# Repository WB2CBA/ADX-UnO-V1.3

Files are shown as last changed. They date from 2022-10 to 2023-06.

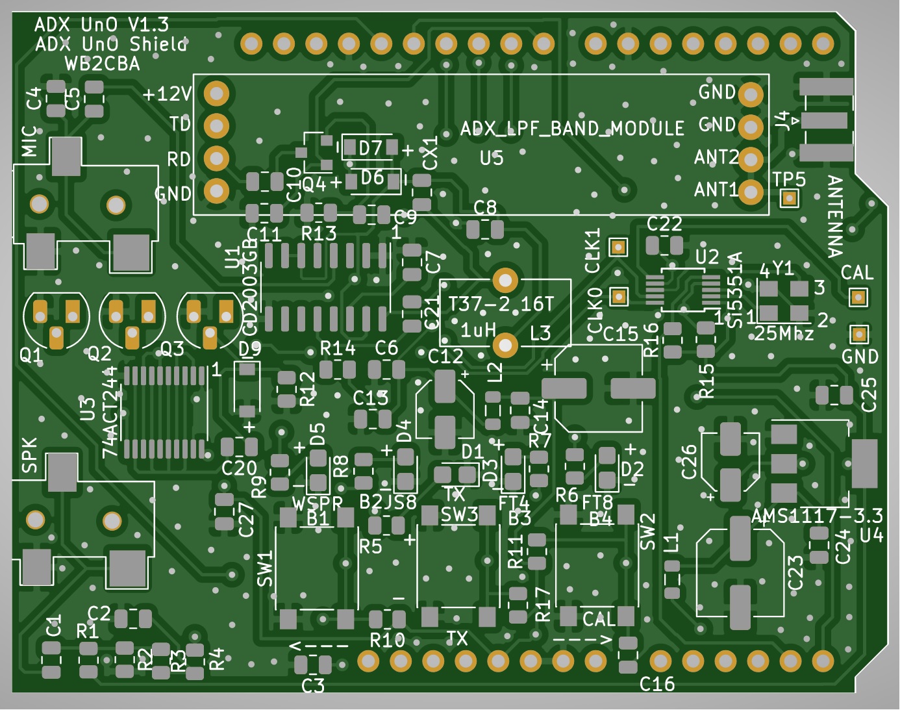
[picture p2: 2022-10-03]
ADX UnO PCB Layouts/ADX Uno Component Layout.jpg

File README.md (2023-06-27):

# ADX-UnO-V1.3

- UPDATE: 27-06-2023

- ADX UnO V1.3 is now fully open source! All SMT production files are under Production Files folder.

- I also added a Guide on how to order SMT manufactured PCBs from JLCPCB PCB production Company.

- ENJOY!:)

ADX UnO is an Arduino Uno based HF Digital Modes Transceiver. ADX is abbreviation for Arduino Digital Xceiver. 

ADX UnO is based on ADX – Arduino based Digital Modes Transceiver design.

https://antrak.org.tr/blog/adx-arduino-digital-transceiver/

ADX UnO is a mono band digital modes optimized HF transceiver that can be plugged on top of an Arduino Uno board to create a 3.5 watts average RF Output power 
QRP portable HF Digital Modes capable transceiver.  ADX UnO can cover four pre-programmed bands one band at a time by swapping Band LPF Filter Modules.

It can operate on any of the pre-programmed four bands of 80m,40m,30m,20m, 17m, 15m and 10m bands and operates on four of the most popular digital modes, FT8, FT4, JS8call and WSPR.

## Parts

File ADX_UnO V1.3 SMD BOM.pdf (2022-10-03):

Comment | Designator | Footprint
100nF | C1,C3,C4,C6,C7,C8,C13,C14,C16,C20,C21,C22,C24,C25,C27 | Capacitor_SMD:C_0805_2012Metric
10uF/16V | C12,C26 | Capacitor_SMD:CP_Elec_4x5.4
100uF/16V | C15,C23 | Capacitor_SMD:CP_Elec_6.3x7.7
10nF | C2,C10,C11 | Capacitor_SMD:C_0805_2012Metric
1uF | C5 | Capacitor_SMD:C_0805_2012Metric
680pF | C9 | Capacitor_SMD:C_0805_2012Metric
TX | D1 | LED_SMD:LED_0805_2012Metric_Castellated
FT8 | D2 | LED_SMD:LED_0805_2012Metric_Castellated
FT4 | D3 | LED_SMD:LED_0805_2012Metric_Castellated
JS8 | D4 | LED_SMD:LED_0805_2012Metric_Castellated
WSPR | D5 | LED_SMD:LED_0805_2012Metric_Castellated
1N4148 | D6,D7,D9 | Diode_SMD:D_SOD-123
SPK | J1 | uSDX_MONO_PCB_Library:Jack_3.5mm_PJ-320B-SMT_Horizontal_CORR
MIC | J2 | uSDX_MONO_PCB_Library:Jack_3.5mm_PJ-320B-SMT_Horizontal_CORR
100uH | L1,L2 | Inductor_SMD:L_0805_2012Metric
MMBF170 | Q4 | Package_TO_SOT_SMD:SOT-23
470k | R1 | Resistor_SMD:R_0805_2012Metric
2.7k | R12 | Resistor_SMD:R_0805_2012Metric
| 100 R14 | Resistor_SMD:R_0805_2012Metric
4.7k | R2,R15,R16 | Resistor_SMD:R_0805_2012Metric
10k | R3,R4,R10,R11,R17 | Resistor_SMD:R_0805_2012Metric
1k | R5,R6,R7,R8,R9,R13 | Resistor_SMD:R_0805_2012Metric
UP | SW1 | Button_Switch_SMD:SW_Push_1P1T_NO_6x6mm_H9.5mm
DOWN/CAL | SW2 | Button_Switch_SMD:SW_Push_1P1T_NO_6x6mm_H9.5mm
TX | SW3 | Button_Switch_SMD:SW_Push_1P1T_NO_6x6mm_H9.5mm
Si5351A | U2 | Package_SO:MSOP-10_3x3mm_P0.5mm
74ACT244 | U3 | Package_SO:TSSOP-20_4.4x6.5mm_P0.65mm
AMS1117-3.3 | U4 | Package_TO_SOT_SMD:SOT-223-3_TabPin2
25Mhz | Y1 | Crystal:Crystal_SMD_SeikoEpson_FA238V-4Pin_3.2x2.5mm

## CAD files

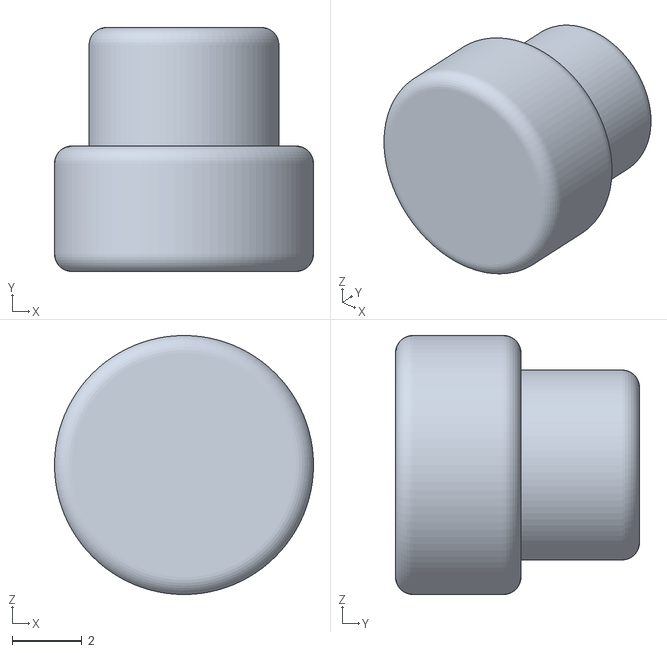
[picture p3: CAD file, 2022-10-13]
ADX UnO 3D printed case Files/KeesButton v4.stl
7.43 x 7.00 x 7.43

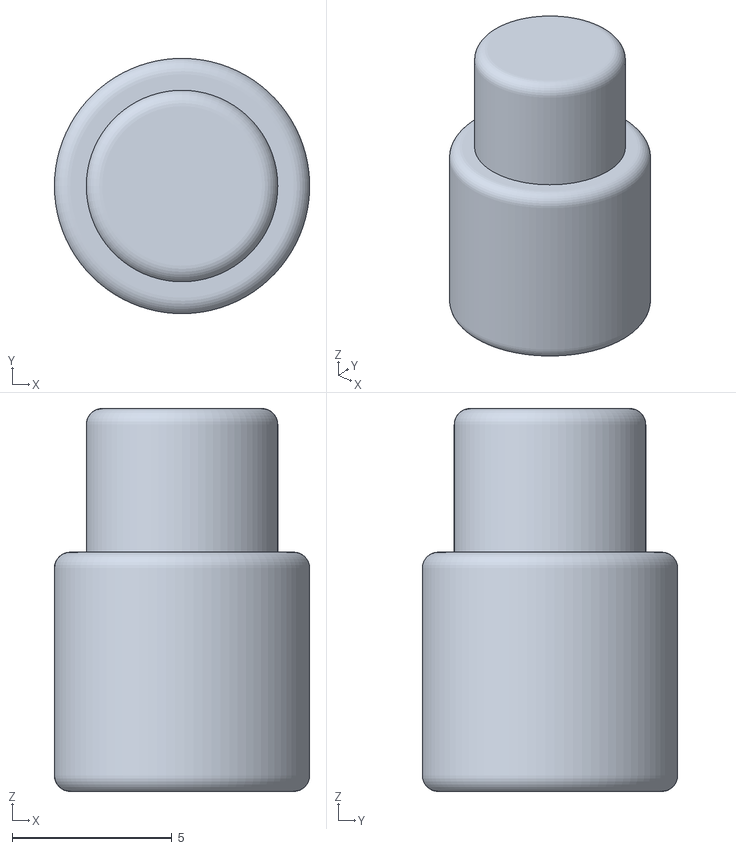
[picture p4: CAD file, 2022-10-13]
ADX UnO 3D printed case Files/button.stl
8.00 x 8.00 x 12.0

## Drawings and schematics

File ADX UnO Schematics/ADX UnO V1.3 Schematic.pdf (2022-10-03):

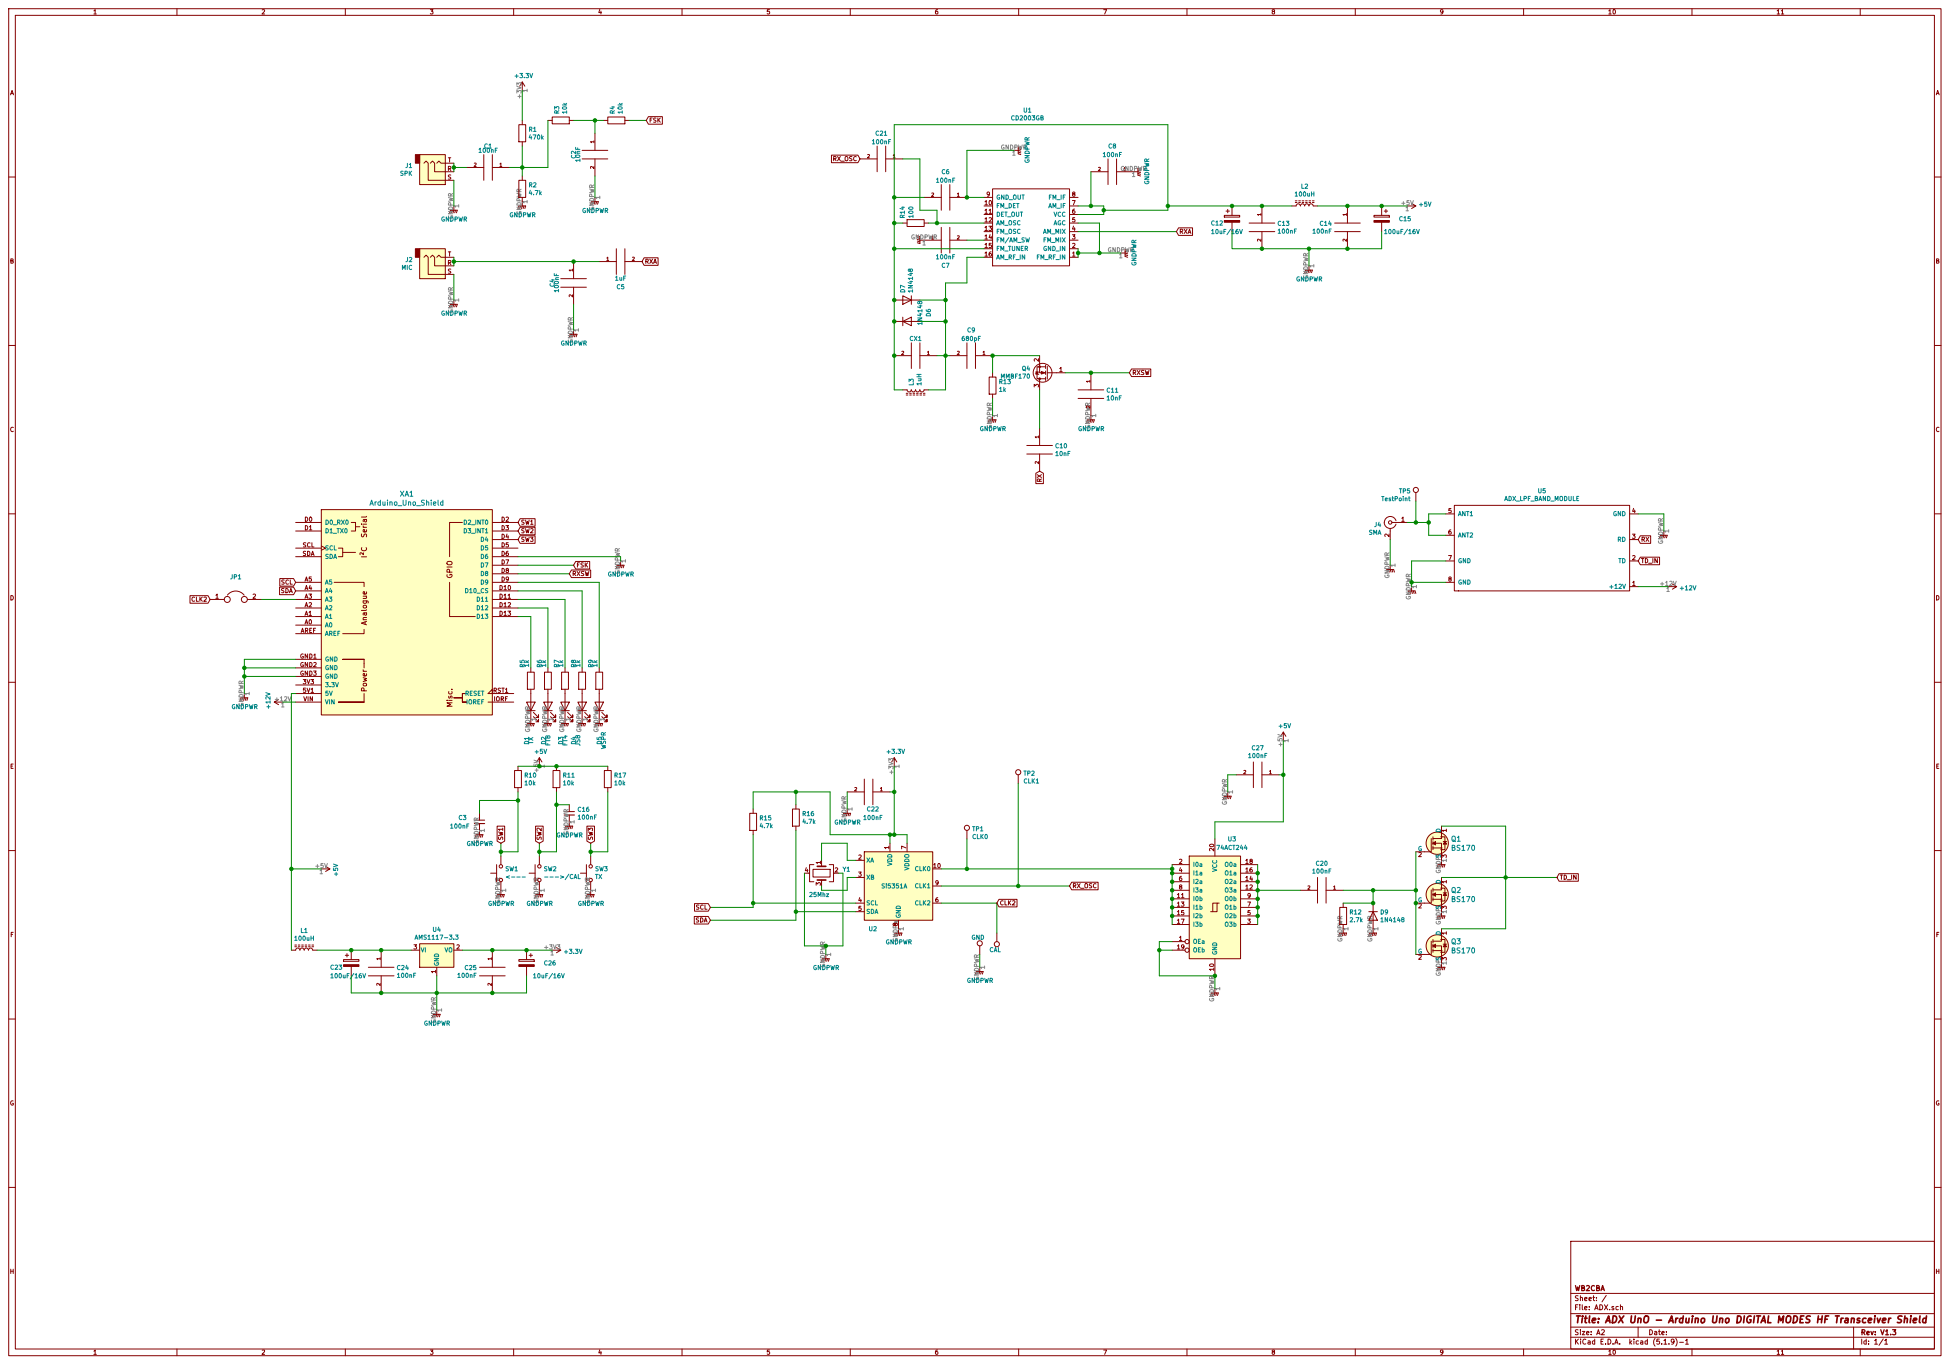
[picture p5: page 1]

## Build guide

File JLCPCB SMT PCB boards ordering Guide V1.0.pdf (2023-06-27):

# SMT PCB boards - JLCPCB ordering guide:

Now let’s talk about the most important subject! How we are going to get these SMD boards manufactured! Here is a short guide for ordering SMD manufactured boards from JLCPCB!

Surface mount parts might be intimidating for most of us. They need healthy eyes and steady hands to solder. This SMT pcb manufacturing service cures that problem by manufacturing PCBs and installing all smd parts on them in a controlled factory environment! An example of cost for this service: uSDX SOTA Main board will cost you less than 15 US Dollars each for a batch of 10 PCB orders including DHL shipping! This means a PCB with 85% of parts assembled including that SI5351 beast! The trick is the more units of pcb you order the less you pay for one pcb in cost.

The reason for that is there are certain one time fee costs JLCPCB adds to their invoice. Those are SMT setting up fee, extended parts fee etc. These are one time cost charges for each pcb order batch. So if we order 5 pieces of pcb that surcharge cost will be shared by 5 pcbs. If we order 30 pcbs then that surcharge will be divided by 30 and will be less per pcb. That’s why it is always order pcbs in larger quantities as a group buy. Ok how we will do this smt ordering business!

I’ll explain this as simple as possible in steps:

1- We will need Production files:
In order to place an order a SMT manufactured PCB from JLCPCB we need three files
– GERBER file (contains all the files to manufacture the PCB board itself)
– BOM File(contains all smd parts, their smd footprints and JLCPCB stock numbers for each part)
– Foot print position file (it is also called as centroid file – coordinates of each smd part on the pcb for pick and place robot)

All these files are included in each boards ZIP file under production file directory.

2- Create an account on www.jlcpcb.com. Follow instructions on their site.

3- After creating your account with all your credentials click on instant quote button

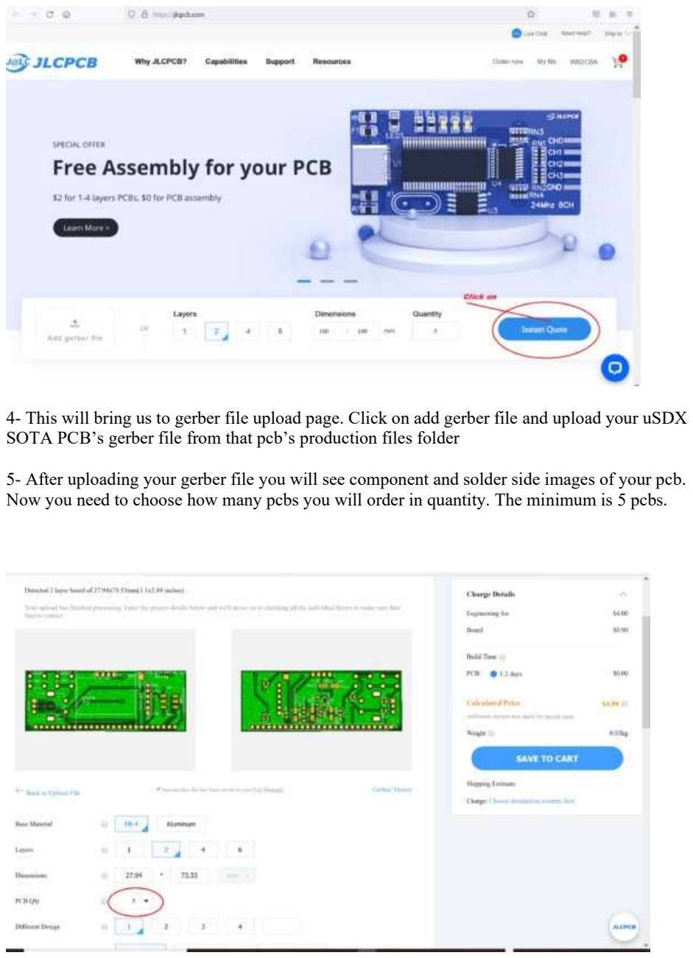
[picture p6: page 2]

4- This will bring us to gerber file upload page. Click on add gerber file and upload your uSDX SOTA PCB’s gerber file from that pcb’s production files folder

5- After uploading your gerber file you will see component and solder side images of your pcb. Now you need to choose how many pcbs you will order in quantity. The minimum is 5 pcbs.

6- Now scroll down the same gerber upload page until you see the Free SMT Assembly for your PCB slide switch which should be light grey inactive position. Now slide it to activate. You should see below screen with top and bottom sides of your PCB. In this case I used uSDX SOTA 128×64 OLED Display as an example. In this display smd populated side is bottom side so I chose assemble bottom side. Now without touching anything else first click on Confirm then click on NEXT.

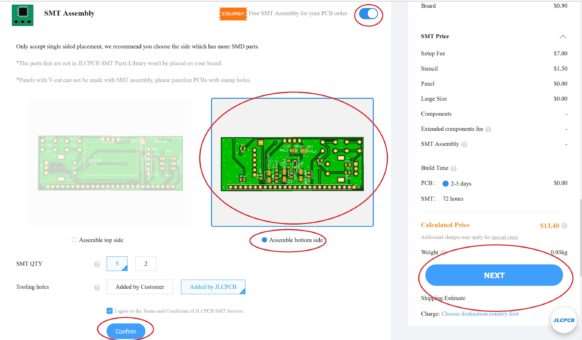
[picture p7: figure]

7- Now we will come to this next screen after clicking on NEXT. This is where we upload our BOM file and footprint position file which is marked as CPL button. These files are in your PCB’s production files. First click on Add BOM File button and upload BOM file from production files folder. Then click on Add CPL File Button and upload your footprint position file from your PCB’s production files.

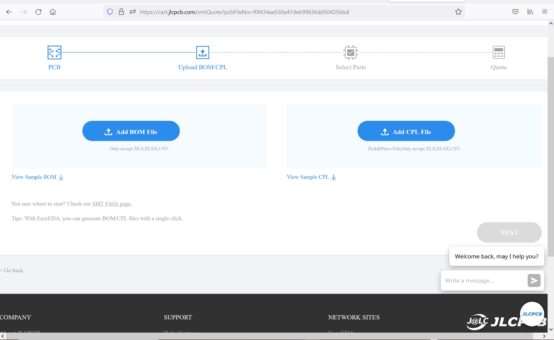
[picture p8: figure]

8- After uploading BOM and CPL files this is the screen which shows all the components of our PCB for SMT manufacturing. This table will show all the component part numbers, total number of each component that will be used for the whole batch of PCBs. Also total cost of each part for the whole batch of PCB order.

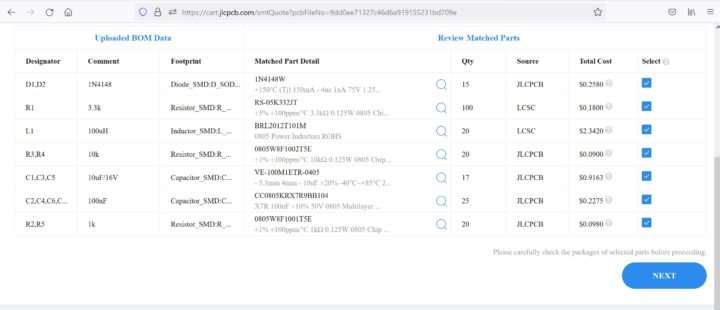
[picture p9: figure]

The most important column in this table is those blue check marks. If you see a blue check mark then it tells you that they have your components and those components have enough stock to manufacture your boards! If one or more parts is not in stock which can happen nowadays as there is chip shortage going on you might get an inventory shortage warning in place of blue check mark. Now JLCPCB does not have that part in stock and can’t pick and place that part and that part will be omitted from pick and place manufacturing. It’s not the end of the world! You can still get your pcb manufactured and hand solder those parts when you receive your pcbs.

Here is an example for that:

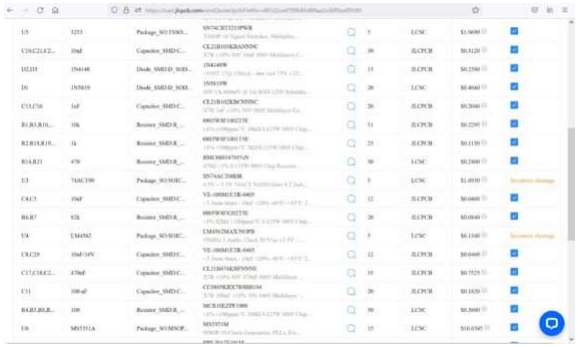
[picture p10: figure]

This is parts list for uSDX SOTA Main PCB. Two parts, 74ACT00DWR and LM4562 is out of stock. The rest of the parts are in stock so no problem with them. We will just order the PCBS and hand solder those parts afterwards. They are easy to solder smd parts.
Now click on NEXT to go to the next ordering screen.

9- This is the next screenshot you will come across which shows your PCB and virtual pick and place finished product layout of your pcb. There might be orientation errors in this PCB virtual parts layout time to time, don’t worry about that. JLCPCB will review your pcb layout and pick and place file and then match those positions. After you ordered your PCB for SMT manufacturing they will review it and correct those mismatches. After this review when you access your account you will see a DFM file icon. If you click on that it will show your previous and manufacturing virtual corrected layout.

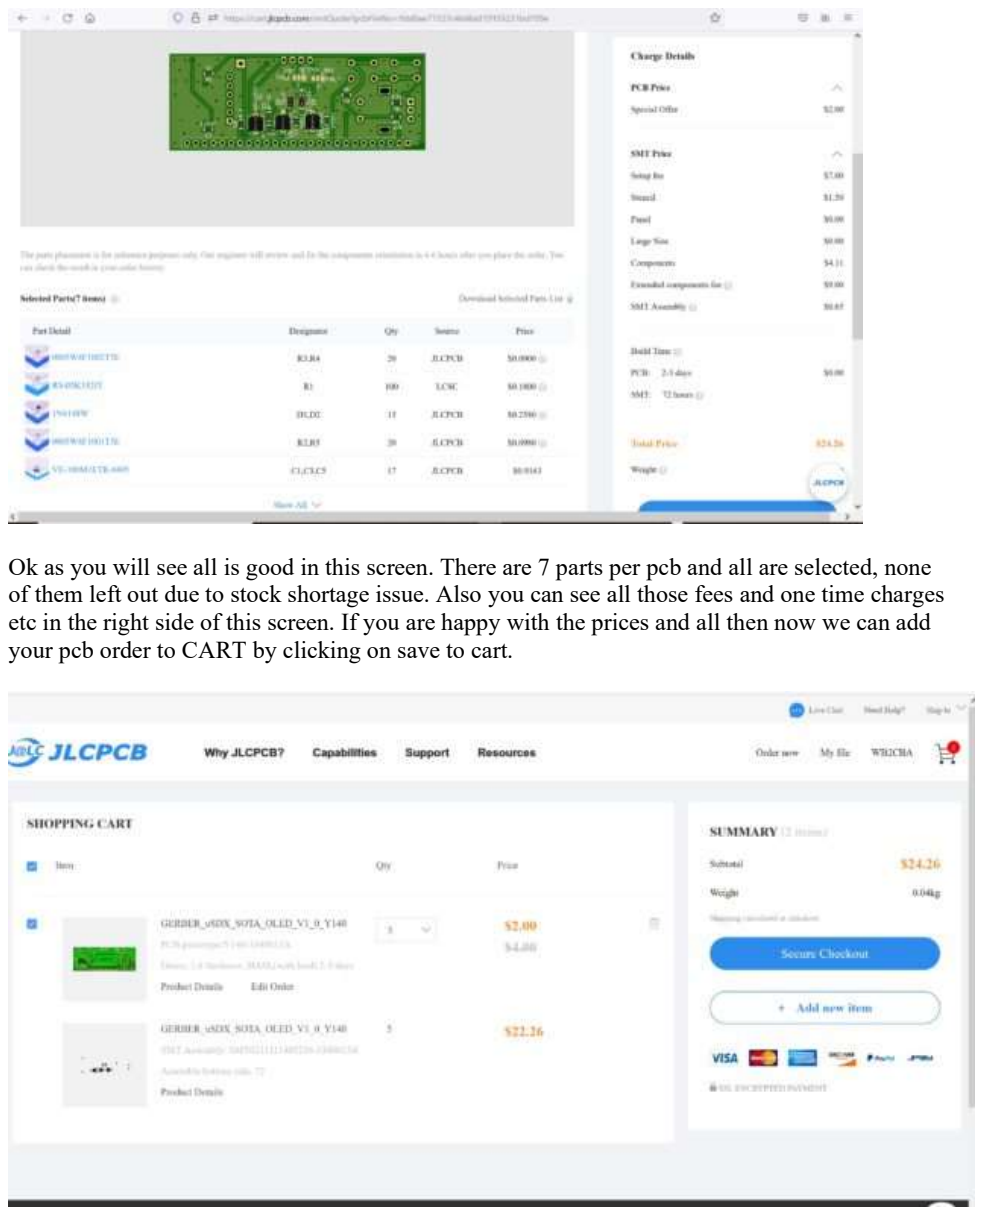
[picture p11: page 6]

Ok as you will see all is good in this screen. There are 7 parts per pcb and all are selected, none of them left out due to stock shortage issue. Also you can see all those fees and one time charges etc in the right side of this screen. If you are happy with the prices and all then now we can add your pcb order to CART by clicking on save to cart.

This CART screen will show your total cost for that ordered pcb batch. Now press on secure checkout and follow the procedure by verifying your address then shipment type and then payment etc.

Now let’s talk again about our nightmare case where some of the parts were out of stock!

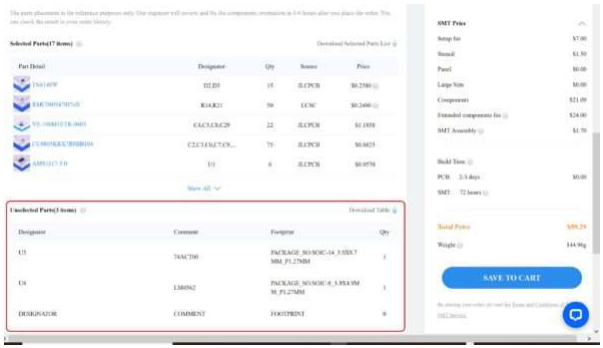
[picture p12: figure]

In uSDX SOTA Main board PCB case two parts were out of stock and we still advanced the order and clicked next. Now as outlined in red box those parts are out of production and not listed on main parts list and will not be shown on virtual smt mounted pcb layout. We can still go ahead with the order and save to cart and get main board pcbs manufactured and when we outsource those parts we can hand solder them. It’s not the end of the world!

Personally I encourage fellow DIY lover hams to give it a try on ordering uSDX SOTA boards smt manufactured from JLCPCB. You will be surprised how cheap they will be for an order of 10 boards. Even with minimum 5 boards is reasonable price. The biggest benefit is that 85% of the transceiver rig is coming to your door step already soldered in!

Barb WB2CBA
12/05/2021 NY, USA

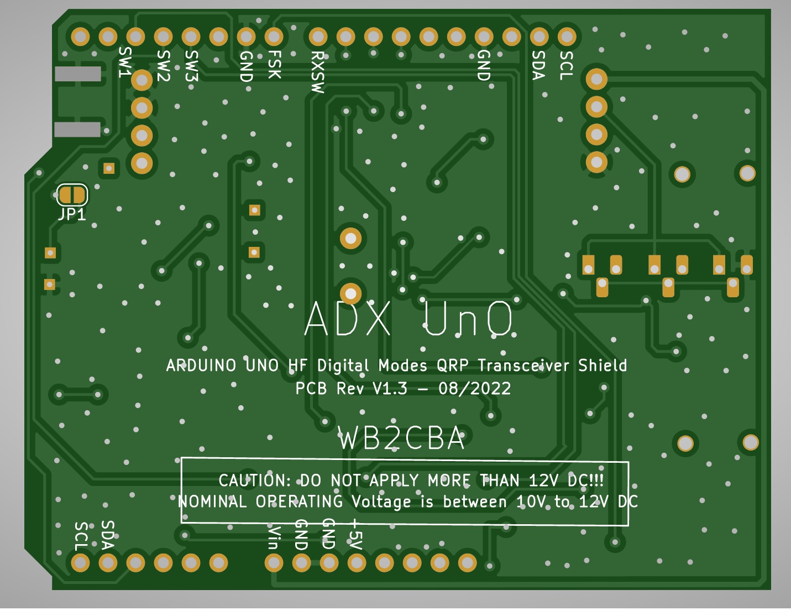
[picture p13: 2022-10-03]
ADX UnO PCB Layouts/ADX Uno Solder side Layout.jpg

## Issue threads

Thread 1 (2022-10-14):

Question about JLCPCB order

gembiart, 2022-10-14:
Hello, I'm trying order PCB (from your gerber files) with BOM xlsx file. On JLCPCB website is also ADD CPL FILE (with coordinates I suppose)
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
Can you share with this CPL file ? I didn't see it at your project.

Regards
SQ5ART

WB2CBA, 2022-10-15:
Hi,

I released ADX Uno as Open source for DIY, meaning anyone can produce a  pcb and build one by reflow or hand solder.
CPL file  is for pick and place mass production and I reserve the rights of pick and place production and I won’t release at least for now. I hope this clarifies your query.

73

Barb WB2CBA

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

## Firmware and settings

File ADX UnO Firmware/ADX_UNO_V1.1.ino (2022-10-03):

//*********************************************************************************************************
//********************* ADX UNO - ARDUINO UNO  DIGITAL MODES 4 BAND HF TRANSCEIVER ***************************
//********************************* Write up start: 02/01/2022 ********************************************
// FW VERSION: ADX_UNO_V1.1 - Version release date: 08/05/2022
// Barb(Barbaros ASUROGLU) - WB2CBA - 2022
//  Version History
//  V1.0  Modified Calibration EEPROM to protect R/W cycle of EEPROM.
//  V1.1 10m/28Mhz band support added.
//*********************************************************************************************************
// Required Libraries
// ----------------------------------------------------------------------------------------------------------------------
// Etherkit Si5351 (Needs to be installed via Library Manager to arduino ide) - SI5351 Library by Jason Mildrum (NT7S) - https://github.com/etherkit/Si5351Arduino
//*****************************************************************************************************
//* IMPORTANT NOTE: Use V2.1.3 of NT7S SI5351 Library. This is the only version compatible with ADX!!!*
//*****************************************************************************************************
// Arduino "Wire.h" I2C library(built-into arduino ide)
// Arduino "EEPROM.h" EEPROM Library(built-into arduino ide)
//*************************************[ LICENCE and CREDITS ]*********************************************
//  FSK TX Signal Generation code by: Burkhard Kainka(DK7JD) - http://elektronik-labor.de/HF/SDRtxFSK2.html
//  SI5351 Library by Jason Mildrum (NT7S) - https://github.com/etherkit/Si5351Arduino

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
//*****************[ SI5351 VFO CALIBRATION PROCEDURE ]****************************************
// For SI5351 VFO Calibration Procedure follow these steps:
// 1 - Connect CAL test point and GND test point on ADX PCB to a Frequency meter or Scope that can measure 1 Mhz up to 1Hz accurately.
// 2 - Press SW2 / --->(CAL) pushbutton and hold.
// 4-  Power up with 12V or with 5V by using arduino USB socket while still pressing SW2 / --->(CAL) pushbutton. 
// 5 - FT8 and WSPR LEDs will flash 3 times and stay lit. Now Release SW2 / --->(CAL). Now Calibration mode is active.
// 6 - Using SW1(<---) and SW2(--->) pushbuttons change the Calibration frequency.
// 7 - Try to read 1 Mhz = 1000000 Hz exact on  Frequency counter or Oscilloscope. 
//     The waveform is Square wave so freqency calculation can be performed esaily.
// 8 - If you read as accurate as possible 1000000 Hz then calibration is done. 
// 9 - Now we must save this calibration value to EEPROM location. 
//     In order to save calibration value, press TX button briefly. TX LED will flash 3 times which indicates that Calibration value is saved.
// 10- Power off ADX.
 
//*******************************[ LIBRARIES ]*************************************************
#include <si5351.h>
#include "Wire.h"
#include <EEPROM.h>
//*******************************[ VARIABLE DECLERATIONS ]*************************************
uint32_t val;
int temp;
uint32_t val_EE; 
int addr = 0;
int mode;
unsigned long freq; 
unsigned long freq1;
int32_t cal_factor;
int TX_State = 0;

unsigned long Cal_freq = 1000000UL; // Calibration Frequency: 1 Mhz = 1000000 Hz
unsigned long F_FT8;
unsigned long F_FT4; 
unsigned long F_JS8;
unsigned long F_WSPR;
int Band_slot;
int Band = 0;
int UP_State;
int DOWN_State;
int TXSW_State;
int Bdly = 250;
// **********************************[ DEFINE's ]***********************************************
#define UP 2    // UP Switch
#define DOWN 3  // DOWN Switch
#define TXSW 4  // TX Switch

#define TX 13 //TX LED
#define WSPR  9 //WSPR LED 
#define JS8  10 //JS8 LED
#define FT4  11 //FT4 LED
#define FT8 12 //FT8 LED

#define RX  8 // RX SWITCH
#define SI5351_REF 		25000000UL  //change this to the frequency of the crystal on your si5351’s PCB, usually 25 or 27 MHz

//**********************************[ BAND SELECT ]************************************************
// ADX can support up to 4 bands on board. Those 4 bands needs to be assigned to Band1 ... Band4 from supported 8 bands.
// To change bands press SW1 and SW2 simultaneously. Band LED will flash 3 times briefly and stay lit for the stored band. also TX LED will be lit to indicate
// that Band select mode is active. Now change band bank by pressing SW1(<---) or SW2(--->). When desired band bank is selected press TX button briefly to exit band select mode. 
// Now the new selected band bank will flash 3 times and then stored mode LED will be lit. 
// TX won't activate when changing bands so don't worry on pressing TX button when changing bands in band mode.

// Assign your prefered bands to B1,B2,B3 and B4
// Supported Bands are: 80m, 40m, 30m, 20m,17m, 15m, 10m

int Band1 = 40; // Band 1 // These are default bands. Feel free to swap with yours
int Band2 = 30; // Band 2
int Band3 = 20; // Band 3
int Band4 = 17; // Band 4

Si5351 si5351;

//*************************************[ SETUP FUNCTION ]************************************** 
void setup()
{
   pinMode(UP, INPUT);
   pinMode(DOWN, INPUT);
   pinMode(TXSW, INPUT);
   
pinMode(TX, OUTPUT);
pinMode(WSPR, OUTPUT);
pinMode(JS8, OUTPUT);
pinMode(FT4, OUTPUT);
pinMode(FT8, OUTPUT);
pinMode(RX, OUTPUT);

pinMode(7, INPUT); //PD7 = AN1 = HiZ, PD6 = AN0 = 0
  
INIT();

//------------------------------- SET SI5351 VFO -----------------------------------  
   // The crystal load value needs to match in order to have an accurate calibration
  si5351.init(SI5351_CRYSTAL_LOAD_8PF, 0, 0);
  si5351.set_correction(cal_factor, SI5351_PLL_INPUT_XO);
 si5351.set_pll(SI5351_PLL_FIXED, SI5351_PLLA);
  si5351.drive_strength(SI5351_CLK0, SI5351_DRIVE_8MA);// SET For Max Power
  si5351.drive_strength(SI5351_CLK1, SI5351_DRIVE_2MA); // Set for reduced power for RX 
  
 if ( digitalRead(DOWN) == LOW ) {
Calibration();
 }
 

  TCCR1A = 0x00;
  TCCR1B = 0x01; // Timer1 Timer 16 MHz
  TCCR1B = 0x81; // Timer1 Input Capture Noise Canceller
  ACSR |= (1<<ACIC);  // Analog Comparator Capture Input
  
  pinMode(7, INPUT); //PD7 = AN1 = HiZ, PD6 = AN0 = 0
          digitalWrite(RX,LOW);

 Mode_assign(); 

}
 
//**************************[ END OF SETUP FUNCTION ]************************

//***************************[ Main LOOP Function ]**************************
void loop()
{  

       UP_State = digitalRead(UP);
          DOWN_State = digitalRead(DOWN);


if ((UP_State == LOW)&&(DOWN_State == LOW)&&(TX_State == 0)) {
   delay(100); 
 UP_State = digitalRead(UP);
    DOWN_State = digitalRead(DOWN);
if ((UP_State == LOW)&&(DOWN_State == LOW)&&(TX_State == 0)) {

    Band_Select();
    
  }
}

  

if ((UP_State == LOW)&&(DOWN_State == HIGH)&&(TX_State == 0)) {
   delay(50); 
     
UP_State = digitalRead(UP);
if ((UP_State == LOW)&&(DOWN_State == HIGH)&&(TX_State == 0)) {
mode = mode - 1;

if (mode < 1){
mode = 4;
}



addr = 40;
 EEPROM.put(addr, mode); 
                Mode_assign();
                
  }} 
   
      DOWN_State = digitalRead(DOWN);

if ((UP_State == HIGH) && (DOWN_State == LOW)&&(TX_State == 0)) {
   delay(50); 
     
DOWN_State = digitalRead(DOWN);
if ((UP_State == HIGH) && (DOWN_State == LOW)&&(TX_State == 0)) {
mode = mode + 1;

if (mode > 4){
mode = 1;
}



addr = 40;
 EEPROM.put(addr, mode); 
                    Mode_assign();
                    
  }} 

  TXSW_State = digitalRead(TXSW);

if ((TXSW_State == LOW) && (TX_State == 0)) {
   delay(50); 
     
TXSW_State = digitalRead(TXSW);
if ((TXSW_State == LOW) && (TX_State == 0)) {
  
Mode_assign();

ManualTX();

           }
  
     }

unsigned int d1,d2;
 int FSK = 10;
 int FSKtx = 0;
 while (FSK>0){
  TCNT1 = 0;
  while (ACSR &(1<<ACO)){
    if (TCNT1>65000) {break;
  }
  }  while ((ACSR &(1<<ACO))==0){
    if (TCNT1>65000) {break;}
  }
  TCNT1 = 0;
  while (ACSR &(1<<ACO)){
    if (TCNT1>65000) {break;}
  }
  d1 = ICR1;  
  while ((ACSR &(1<<ACO))==0){
    if (TCNT1>65000) {break;}
  } 
  while (ACSR &(1<<ACO)){
    if (TCNT1>65000) {break;}
  }
  d2 = ICR1;
  if (TCNT1 < 65000){
  unsigned long codefreq = 1600000000/(d2-d1);
    if (codefreq < 350000){
      if (FSKtx == 0){
        TX_State = 1;
          digitalWrite(TX,HIGH);
          digitalWrite(RX,LOW);
         
          si5351.output_enable(SI5351_CLK1, 0);   //RX off
          si5351.output_enable(SI5351_CLK0, 1);   // TX on
      }
      si5351.set_freq((freq * 100 + codefreq), SI5351_CLK0);  
      
      FSKtx = 1;
    }
  }
  else{
    FSK--;
  }
 }
  digitalWrite(TX,0);
  
    si5351.output_enable(SI5351_CLK0, 0);   //TX off
    si5351.set_freq(freq*100ULL, SI5351_CLK1);
          si5351.output_enable(SI5351_CLK1, 1);   //RX on
    TX_State = 0;
    digitalWrite(RX,HIGH);
  FSKtx = 0;

     
}
//*********************[ END OF MAIN LOOP FUNCTION ]*************************

//********************************************************************************
//******************************** [ FUNCTIONS ] *********************************
//********************************************************************************


//************************************[ MODE Assign ]**********************************

void Mode_assign(){
  
addr = 40;
EEPROM.get(addr,mode);


if ( mode == 1){
  freq1 = F_WSPR;
 digitalWrite(WSPR, HIGH); 
     digitalWrite(JS8, LOW); 
         digitalWrite(FT4, LOW); 
             digitalWrite(FT8, LOW); 

}

if ( mode == 2){
  freq1 = F_JS8;
digitalWrite(WSPR, LOW); 
     digitalWrite(JS8, HIGH); 
         digitalWrite(FT4, LOW); 
             digitalWrite(FT8, LOW); 


  
}

if ( mode == 3){
  freq1 = F_FT4;

digitalWrite(WSPR, LOW); 
     digitalWrite(JS8, LOW); 
         digitalWrite(FT4, HIGH); 
             digitalWrite(FT8, LOW); 

  
}
if ( mode == 4){
  freq1 = F_FT8;
  
digitalWrite(WSPR, LOW); 
     digitalWrite(JS8, LOW); 
         digitalWrite(FT4, LOW); 
             digitalWrite(FT8, HIGH); 

  
}
freq = freq1; 
//freq = freq1 - 1000;

}

//********************************[ END OF MODE ASSIGN ]*******************************

//*********************[ Band dependent Frequency Assign Function ]********************
void Freq_assign(){


//---------- 80m/3.5Mhz 
          if (Band == 80){

            F_FT8 = 3573000;
            F_FT4 = 3575000;
            F_JS8 = 3578000;
            F_WSPR = 3568600;
          }

//---------- 40m/7 Mhz 
          if (Band == 40){

            F_FT8 = 7074000;
            F_FT4 = 7047500;
            F_JS8 = 7078000;
            F_WSPR = 7038600;
          }


//---------- 30m/10 Mhz 
          if (Band == 30){

            F_FT8 = 10136000;
            F_FT4 = 10140000;
            F_JS8 = 10130000;
            F_WSPR = 10138700;
          }


//---------- 20m/14 Mhz 
          if (Band == 20){

            F_FT8 = 14074000;
            F_FT4 = 14080000;
            F_JS8 = 14078000;
            F_WSPR = 14095600;
          }


 //---------- 17m/18 Mhz 
          if (Band == 17){

            F_FT8 = 18100000;
            F_FT4 = 18104000;
            F_JS8 = 18104000;
            F_WSPR = 18104600;
          } 

//---------- 15m/ 21Mhz 
          if (Band == 15){

            F_FT8 = 21074000;
            F_FT4 = 21140000;
            F_JS8 = 21078000;
            F_WSPR = 21094600;
          } 
          
//---------- 10m/ 28Mhz 
          if (Band == 10){

            F_FT8 = 28074000;
            F_FT4 = 28180000;
            F_JS8 = 28078000;
            F_WSPR = 28124600;
          }
                     
}
//************************[ End of Frequency assign function ]*************************  

//******************************[ Band  Assign Function ]******************************

void Band_assign(){
digitalWrite(WSPR, LOW); 
     digitalWrite(JS8, LOW); 
         digitalWrite(FT4, LOW); 
             digitalWrite(FT8, LOW); 


addr = 50;
EEPROM.get(addr,Band_slot);

if (Band_slot == 1){
  Band = Band1;
  
digitalWrite(WSPR, HIGH); 
delay(Bdly);
digitalWrite(WSPR, LOW); 
delay(Bdly);
digitalWrite(WSPR, HIGH); 
delay(Bdly);
digitalWrite(WSPR, LOW); 
delay(Bdly);
digitalWrite(WSPR, HIGH); 
delay(Bdly);
digitalWrite(WSPR, LOW); 
delay(Bdly);
}

if (Band_slot == 2){
  Band = Band2;
  
digitalWrite(JS8, HIGH); 
delay(Bdly);
digitalWrite(JS8, LOW); 
delay(Bdly);
digitalWrite(JS8, HIGH); 
delay(Bdly);
digitalWrite(JS8, LOW); 
delay(Bdly);
digitalWrite(JS8, HIGH); 
delay(Bdly);
digitalWrite(JS8, LOW); 
delay(Bdly);
}

if (Band_slot == 3){
  Band = Band3;
  
digitalWrite(FT4, HIGH); 
delay(Bdly);
digitalWrite(FT4, LOW); 
delay(Bdly);
digitalWrite(FT4, HIGH); 
delay(Bdly);
digitalWrite(FT4, LOW); 
delay(Bdly);
digitalWrite(FT4, HIGH); 
delay(Bdly);
digitalWrite(FT4, LOW); 
delay(Bdly);
}

if (Band_slot == 4){
  Band = Band4;
  
digitalWrite(FT8, HIGH); 
delay(Bdly);
digitalWrite(FT8, LOW); 
delay(Bdly);
digitalWrite(FT8, HIGH); 
delay(Bdly);
digitalWrite(FT8, LOW); 
delay(Bdly);
digitalWrite(FT8, HIGH); 
delay(Bdly);
digitalWrite(FT8, LOW); 
delay(Bdly);
}


delay(1000);

Freq_assign();

Mode_assign();


}
//***************************[ End of Band assign function ]***************************  


//*******************************[ Manual TX FUNCTION ]********************************
void ManualTX(){
 
 digitalWrite(RX,LOW);
          si5351.output_enable(SI5351_CLK1, 0);   //RX off


TXON:  

TXSW_State = digitalRead(TXSW);

 
digitalWrite(TX,1);
    si5351.set_freq(freq1*100ULL, SI5351_CLK0);
    si5351.output_enable(SI5351_CLK0, 1);   //TX on
    TX_State = 1;
    
  if (TXSW_State == HIGH) {
goto EXIT_TX;

}
   goto TXON;




EXIT_TX:
digitalWrite(TX,0); 
    si5351.output_enable(SI5351_CLK0, 0);   //TX off
    TX_State = 0;

}

//********************************[ END OF Manual TX ]*********************************

//******************************[ BAND SELECT Function]********************************
void Band_Select(){

digitalWrite(TX,1);
addr = 50; 
EEPROM.get(addr,Band_slot);

digitalWrite(WSPR,LOW); 
digitalWrite(JS8, LOW); 
digitalWrite(FT4, LOW); 
digitalWrite(FT8, LOW); 


if (Band_slot == 1){
 
  
digitalWrite(WSPR, HIGH); 
delay(Bdly);
digitalWrite(WSPR, LOW); 
delay(Bdly);
digitalWrite(WSPR, HIGH); 
delay(Bdly);
digitalWrite(WSPR, LOW); 
delay(Bdly);
digitalWrite(WSPR, HIGH); 
delay(Bdly);
digitalWrite(WSPR, LOW); 
delay(Bdly);
}

if (Band_slot == 2){
  
digitalWrite(JS8, HIGH); 
delay(Bdly);
digitalWrite(JS8, LOW); 
delay(Bdly);
digitalWrite(JS8, HIGH); 
delay(Bdly);
digitalWrite(JS8, LOW); 
delay(Bdly);
digitalWrite(JS8, HIGH); 
delay(Bdly);
digitalWrite(JS8, LOW); 
delay(Bdly);
}

if (Band_slot == 3){
  
digitalWrite(FT4, HIGH); 
delay(Bdly);
digitalWrite(FT4, LOW); 
delay(Bdly);
digitalWrite(FT4, HIGH); 
delay(Bdly);
digitalWrite(FT4, LOW); 
delay(Bdly);
digitalWrite(FT4, HIGH); 
delay(Bdly);
digitalWrite(FT4, LOW); 
delay(Bdly);
}

if (Band_slot == 4){
  
digitalWrite(FT8, HIGH); 
delay(Bdly);
digitalWrite(FT8, LOW); 
delay(Bdly);
digitalWrite(FT8, HIGH); 
delay(Bdly);
digitalWrite(FT8, LOW); 
delay(Bdly);
digitalWrite(FT8, HIGH); 
delay(Bdly);
digitalWrite(FT8, LOW); 
delay(Bdly);
}

Band_cont:
 
if (Band_slot == 1){
 
  
digitalWrite(WSPR, HIGH); 
digitalWrite(JS8, LOW); 
digitalWrite(FT4, LOW); 
digitalWrite(FT8, LOW); 
}

if (Band_slot == 2){
  
  
digitalWrite(JS8, HIGH); 
digitalWrite(WSPR, LOW); 
digitalWrite(FT4, LOW); 
digitalWrite(FT8, LOW); 

}

if (Band_slot == 3){
digitalWrite(FT4, HIGH); 
digitalWrite(WSPR, LOW); 
digitalWrite(JS8, LOW); 
digitalWrite(FT8, LOW); 

  

}

if (Band_slot == 4){
digitalWrite(JS8, LOW); 
digitalWrite(WSPR, LOW); 
digitalWrite(FT4, LOW); 
digitalWrite(FT8, HIGH); 
 
  }


 UP_State = digitalRead(UP);
          DOWN_State = digitalRead(DOWN);
    
if ((UP_State == LOW)&&(DOWN_State == HIGH)) {
   delay(100); 
     
UP_State = digitalRead(UP);
if ((UP_State == LOW)&&(DOWN_State == HIGH)) {
Band_slot = Band_slot - 1;

if (Band_slot < 1){
Band_slot = 4;
        }
     }
  } 
   
if ((UP_State == HIGH)&&(DOWN_State == LOW)) {
   delay(100); 
     
DOWN_State = digitalRead(DOWN);
if ((UP_State == HIGH)&&(DOWN_State == LOW)) {
Band_slot = Band_slot + 1;

if (Band_slot > 4){
Band_slot = 1;
       }
    }
 }
                                                

TX_State = digitalRead(TXSW);

if (TX_State == LOW) {
   delay(100); 
 
    TX_State = digitalRead(TXSW);
if (TX_State == LOW) {
  
digitalWrite(TX,0); 

   goto Band_exit;
    
  }
} 

goto Band_cont;

Band_exit:

addr = 50;
 EEPROM.put(addr, Band_slot); 


 Band_assign();


}
  
//*********************************[ END OF BAND SELECT ]*****************************




//************************** [SI5351 VFO Calibration Function] ************************

void Calibration(){

digitalWrite(FT8, LOW);
digitalWrite(FT4, LOW);
digitalWrite(JS8, LOW);
digitalWrite(WSPR, LOW);

digitalWrite(WSPR, HIGH); 
digitalWrite(FT8, HIGH);
delay(100);        
 
digitalWrite(WSPR, LOW); 
digitalWrite(FT8, LOW);
delay(100);                 


digitalWrite(WSPR, HIGH); 
digitalWrite(FT8, HIGH);
delay(100);        
 
digitalWrite(WSPR, LOW); 
digitalWrite(FT8, LOW);
delay(100);                       

 digitalWrite(WSPR, HIGH); 
digitalWrite(FT8, HIGH);
delay(100);        
 
digitalWrite(WSPR, LOW); 
digitalWrite(FT8, LOW);
delay(100);                       

digitalWrite(WSPR, HIGH); 
digitalWrite(FT8, HIGH);
delay(100);        
 
digitalWrite(WSPR, LOW); 
digitalWrite(FT8, LOW);
delay(100);                       

digitalWrite(WSPR, HIGH); 
digitalWrite(FT8, HIGH);

addr = 10;
EEPROM.get(addr, cal_factor); 

Calibrate:

    UP_State = digitalRead(UP);

if (UP_State == LOW) {
   delay(50); 
     
UP_State = digitalRead(UP);
if (UP_State == LOW) {

cal_factor = cal_factor - 100;

  si5351.set_correction(cal_factor, SI5351_PLL_INPUT_XO);
  
  
  // Set CLK2 output
  si5351.set_freq(Cal_freq * 100, SI5351_CLK2);
  si5351.drive_strength(SI5351_CLK2, SI5351_DRIVE_2MA); // Set for lower power for calibration
  si5351.set_clock_pwr(SI5351_CLK2, 1); // Enable the clock for calibration

  
  }} 
   
    DOWN_State = digitalRead(DOWN);

if (DOWN_State == LOW) {
   delay(50);   
   
         DOWN_State = digitalRead(DOWN);
if (DOWN_State == LOW) {

cal_factor = cal_factor + 100;
    
  si5351.set_correction(cal_factor, SI5351_PLL_INPUT_XO);
  
  // Set CLK2 output
  si5351.set_freq(Cal_freq * 100, SI5351_CLK2);
  si5351.drive_strength(SI5351_CLK2, SI5351_DRIVE_2MA); // Set for lower power for Calibration
  si5351.set_clock_pwr(SI5351_CLK2, 1); // Enable clock2 

  }}

    TXSW_State = digitalRead(TXSW);

if (TXSW_State == LOW) {
   delay(50);   
   
         TXSW_State = digitalRead(TXSW);
if (TXSW_State == LOW) {
  
addr = 10;
EEPROM.put(addr, cal_factor); 

digitalWrite(TX, HIGH); 
delay(Bdly);
digitalWrite(TX, LOW); 
delay(Bdly);
digitalWrite(TX, HIGH); 
delay(Bdly);
digitalWrite(TX, LOW); 
delay(Bdly);
digitalWrite(TX, HIGH); 
delay(Bdly);
digitalWrite(TX, LOW); 

    
  }} 

   goto Calibrate;
      }

//****************************** [ End Of Calibration Function ]****************************************

//*********************************[ INITIALIZATION FUNCTION ]******************************************
void INIT(){

 addr = 30;
EEPROM.get(addr,temp);

if (temp != 100){
  
addr = 10; 
cal_factor = 100000;
EEPROM.put(addr, cal_factor); 

addr = 40;
temp = 4;
EEPROM.put(addr,temp);

addr = 30;
temp = 100;
EEPROM.put(addr,temp);

addr = 50;
temp = 1;
EEPROM.put(addr,temp);

        }

else

{
//--------------- EEPROM INIT VALUES
addr = 30;
EEPROM.get(addr,temp);

addr = 10;
EEPROM.get(addr,cal_factor);

addr = 40;
EEPROM.get(addr,mode);

addr = 50;
EEPROM.get(addr,Band_slot);


    }  

Band_assign();

Freq_assign();

Mode_assign();

 si5351.set_clock_pwr(SI5351_CLK2, 0); // Turn off Calibration Clock

}
//********************************[ END OF INITIALIZATION FUNCTION ]*************************************
